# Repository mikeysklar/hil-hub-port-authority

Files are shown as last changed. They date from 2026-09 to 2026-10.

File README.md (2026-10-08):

# hil-hub-port-authority

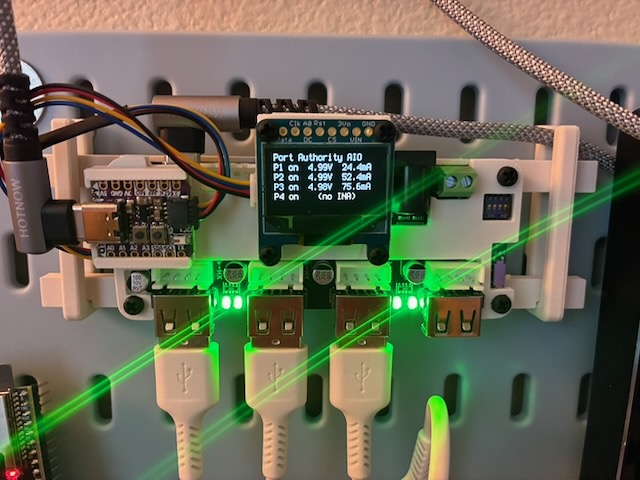
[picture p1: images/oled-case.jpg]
Port Authority hub in the OLED display case, showing live voltage and current per port (https://drive.google.com/file/d/1w-OZUrAUlDJJefoLmWJcbIFCo_5FYicz/view?usp=sharing)


[▶ Watch the video](https://drive.google.com/file/d/1w-OZUrAUlDJJefoLmWJcbIFCo_5FYicz/view?usp=sharing)

Test notes, scripts and cases for the **Port Authority** 4-port USB hub
(Adafruit Smart HIL Hub Rev C), first JLC run, tested 2026-09-24 to 2026-10-01.

USB2514B hub with per-port power switching (`uhubctl`), INA3221 current
monitoring on ports 1-3, two STEMMA QT ports, external 5 V input and DIP
config modes.

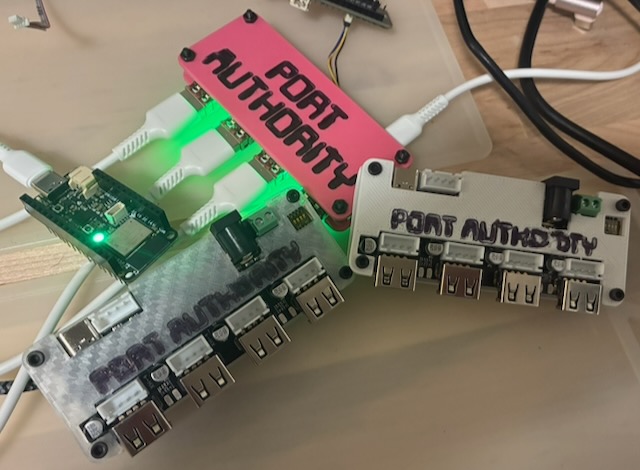
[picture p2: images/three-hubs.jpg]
Three Port Authority hubs in sandwich cases


Short summary: [docs/testing-summary.md](docs/testing-summary.md).

## Works

| Feature | Result |
|---|---|
| Per-port power | Clean cutoffs, Linux and macOS, no sudo |
| Power cycling | Feather M0, RP2040, RP2350, ESP32 V2 |
| Current monitoring | Ports 1-3, within ~5% of a USB meter |
| Port current | 1.17 A+ continuous per port |
| Green port LEDs | Follow port power |
| SW1 reset, external 5 V | Both work |
| DIP `0 0 0 1` | Reports bus-powered |
| EEPROM mode `1 1 1 1` | Works once programmed; custom name and serial |
| STEMMA2 + OLED | Live per-port status display |
| SWD through the hub | RP2350 flash and verify in 11.2 s |
| USB chaining | Works, see concern 2 |

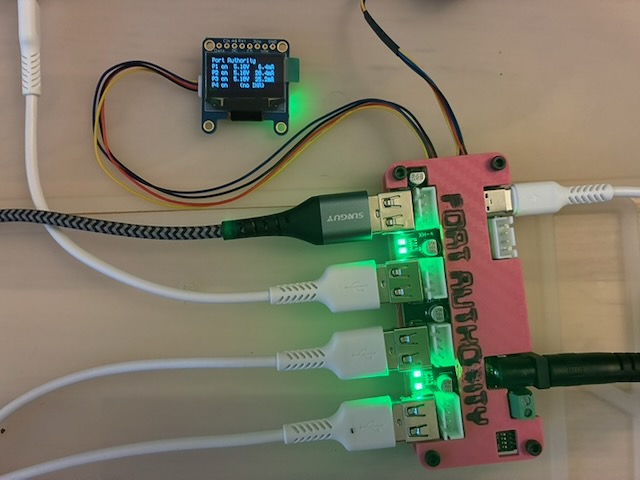
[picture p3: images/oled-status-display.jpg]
OLED on STEMMA2 showing live voltage and current per port


## Concerns

1. **STEMMA QT V+ back-feeds an unpowered controller.** Its 3.3 V rail sits
   at 0.98 V with its port off; a Feather RP2040 lands in the bootloader
   about 1 in 10 boots. Path: hub 3.3 V through the BSS138 body diode and
   QT-side pull-ups onto V+. With only the V+ wire cut: 0 V, 33/33 clean.
   Fix: a diode on STEMMA1 V+, controller on STEMMA1, add-ons on STEMMA2.
   Now: keep the controller always powered.
2. **A chained hub with an ESP32 V2 never recovers after its upstream port
   is cut.** It loops connect/disconnect forever. Fine empty, with native-USB
   boards, or with the V2 on the top-level hub. Keep USB-serial boards on the
   top-level hub.

## Doesn't work

- SMBus DIP mode `1 1 1 0`: hub never enumerates. Parked.
- EEPROM mode as shipped: the EEPROM is blank. Program it with
  `test-scripts/eeprom_write.py`.
- Pi 4 plus drive on one port browns out at 1.24 A peaks.

## Untested

- I2C chaining (needs the A0 jumper)
- Red fault LED
- JST-XH connectors

## Linux setup

Full notes: [docs/host-setup.md](docs/host-setup.md).

- `apt install uhubctl` plus udev rules for the hub and the per-port
  `disable` files. Don't use `uhubctl -S`.
- Address boards by `/dev/serial/by-path`, not `ttyACM` numbers.
- SWD on RP2350 needs the [raspberrypi openocd fork](https://github.com/raspberrypi/openocd).

## Repo

| Path | Contents |
|---|---|
| [docs/](docs/) | findings, full test log, test plan, host setup, summary |
| [test-scripts/](test-scripts/) | test scripts, see its README |
| [case/sandwich/](case/sandwich/) | two-plate case: FreeCAD script, FCStd, STEP, 3MF |
| [case/skadis/](case/skadis/) | IKEA SKADIS frame: FreeCAD script, FCStd, STEP, 3MF, STL |
| [case/display/](case/display/) | top plate with QT Py ESP32-S3 cradle and OLED mount, rail frame, heat-set inserts: FreeCAD script, FCStd, STEP |

Build a case with `freecadcmd build_case.py`; it also writes the STLs left
out of the repo.

| | |
|---|---|
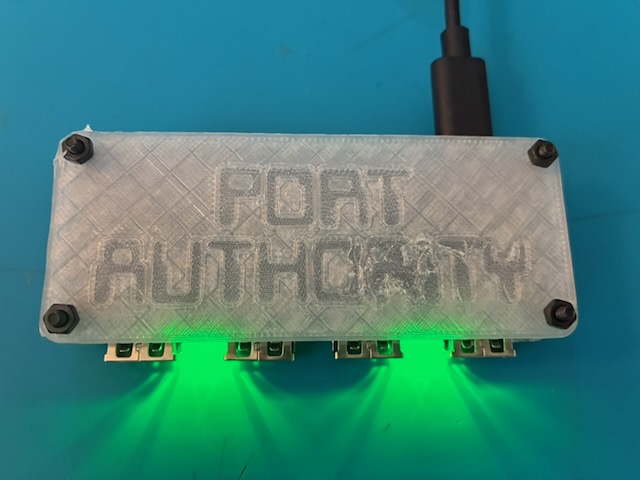
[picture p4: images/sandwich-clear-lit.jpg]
Clear sandwich case with port LEDs lit
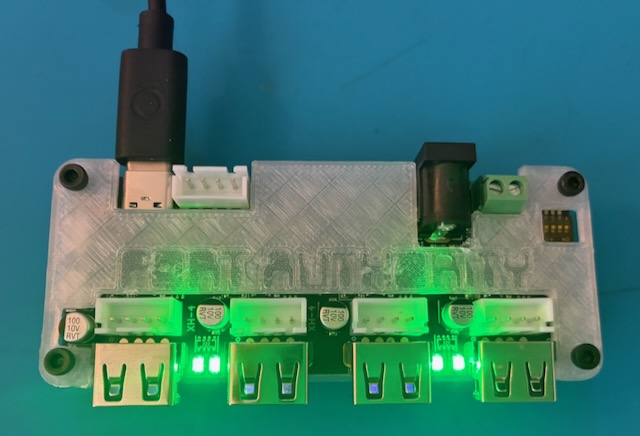
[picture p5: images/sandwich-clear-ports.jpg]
Clear case, connector side
|  |  |
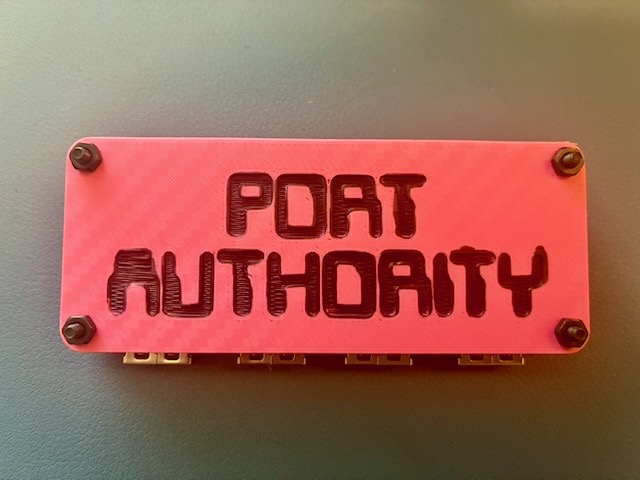
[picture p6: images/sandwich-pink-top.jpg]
Pink sandwich case, top plate
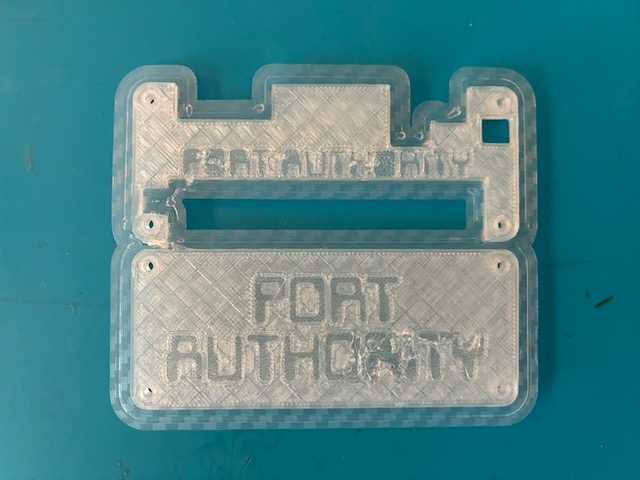
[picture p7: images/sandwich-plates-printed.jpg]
Printed top and bottom plates
|  |  |
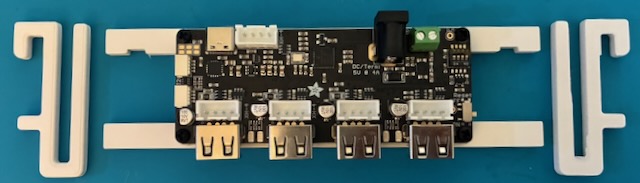
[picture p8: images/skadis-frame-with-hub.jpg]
Hub on the SKADIS frame with pegboard hooks
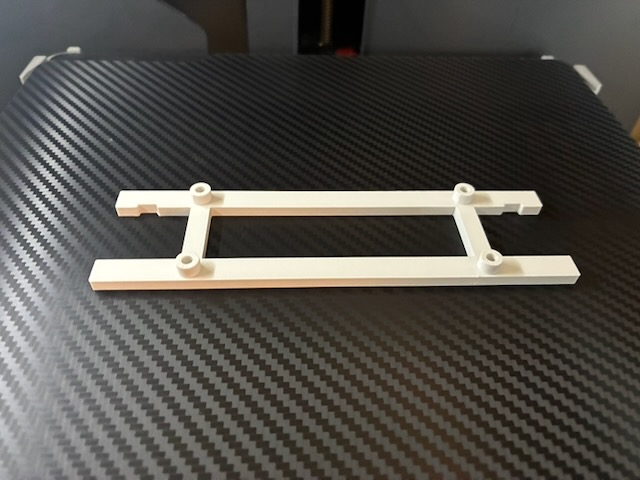
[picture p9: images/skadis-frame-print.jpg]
Printed SKADIS frame with heat-set insert bosses
|  |  |

## License

MIT, see [LICENSE](LICENSE).

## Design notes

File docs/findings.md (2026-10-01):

# Port Authority (Smart HIL Hub Rev C): findings

Running summary for the final report. Evidence and raw output for every row
are in `test-log.md` and `results/`; scripts in `test-scripts/`. Boards tested:
hub A and hub B from the 10-board JLC run, design at commit `461a9006b`.

Status: **Works** confirmed on hardware, **Problem** confirmed, **Open**
not yet tested or not conclusive.

## Hub features

| Feature | Status | Result |
|---|---|---|
| USB enumeration (USB2514B, Multi-TT, 4 ports) | Works | `0424:2514`, TT per port, per-port power and over-current reported |
| Per-port power switching (uhubctl) | Works | Every cutoff clean on both hubs (port reads `0000 off`, board drops, VBUS 0.000 V measured) |
| Hub reset slide switch SW1 | Works | Hub and all ports drop and return; ports are power-cycled too |
| I2C via STEMMA QT, INA3221 at 0x40 | Works | ID registers read `TI` / `3220` |
| Current monitoring, ports 1-3 | Works | Channel N = port N, no crosstalk, 0 mA / 0 V when off; port 4 unmonitored by design |
| External 5 V input (barrel jack) | Works | Hot-plug without disconnect; 4 A supply as stiff as USB-C |
| Bus-powered mode, DIP `0 0 0 1` | Works | Reports `0xa0` Bus Powered, MaxPower 100 mA; per-port switching unchanged. Default `0 0 0 0` reports Self Powered regardless of source, by design |
| USB serial number | Works with EEPROM | Ships with none (two hubs only told apart by USB path). With a programmed EEPROM and DIP `1 1 1 1` the hub reports a serial, e.g. `PA-A` |
| STEMMA2 pass-through | Works | OLED on STEMMA2 scans at 0x3D alongside the INA3221 at 0x40, same bus as STEMMA1 |
| INA3221 accuracy vs meter | Rough check | Battery pack charging on port 2: INA3221 1.15-1.17 A, user's meter 1.2 A (within ~5%). One point only; no low-current check |
| Port LEDs, green | Works | Follows uhubctl port power on/off (user, daily use) |
| Over-current limit and red LED | Works well enough, red not pursued | Ports deliver at least 1.17 A continuously, beyond the ~1 A design target. Red LED never triggered and not tested further (decision 2026-10-01). Red = AP22653 FAULT (also OCS to the hub), after a ~6 ms blanking time, auto-recovering. Battery pack held 1.17 A for 30 s with green LED and no OC reported; Pi 4 + drive peaked 1.10-1.24 A briefly without a fault. |
| Port power under heavy load | Note | Pi 4 + external drive on one port: 0.65 A idle, 0.9-1.0 A busy, peaks to 1.24 A; port sagged to 3.87 V and the Pi browned out and rebooted twice with no fault flagged. Whole-hub supply sagged too (another port 5.10 V to 4.69-4.82 V) on the 4 A barrel. Guide: Pi-class loads are at this port's edge |
| SMBus mode, DIP `1 1 1 0` | Problem, parked | Hub stays off USB but never answers at 0x2C. See problems below |
| EEPROM mode, DIP `1 1 1 1` | Works once programmed | EEPROM ships blank and the hub then fails to enumerate. `eeprom_write.py` (hub held in reset with SW1, DIP 1 2 3 on) wrote a datasheet-default image with strings; hub A now enumerates as Adafruit Industries / Port Authority / PA-A, Multi-TT, all ports working |
| JST-XH per-port connectors | Open | |
| Chaining two hubs, USB | Works, with a restriction | Hub B on hub A port 4: nested uhubctl path `1-1.4` works, hub B ports switch 5/5, cutting hub A port 4 power-cycles hub B and its boards (empty 6/6, Feather RP2040 5/5, thumb drive 5/5). **Restriction:** with an ESP32 V2 on hub B, hub B never recovers from that cut (see problems). Keep USB-serial boards on the top-level hub, or switch their own port instead |
| Chaining two hubs, I2C | Open | Needs hub B's INA3221 A0 jumper bridged (0x41) |
| I2C display on STEMMA | Works | Adafruit 326 (0.96" 128x64 SSD1306, 0x3D) on STEMMA2: `controller/oled_ports.py` shows V/mA for ports 1-3 from the INA3221; `oled_push.py` sends on/off for all 4 from uhubctl. Port changes show within about a second |
| SWD / openocd through the hub | Works | Feather RP2350: attach, `reset halt`, resume; `cannot read IDR` with the port off. 30/30 clean power cycles with the probe attached (no back-feed). RP2350 needs the raspberrypi openocd fork |
| macOS | Works (user report) | Daily use on a Mac mini M4 Pro, macOS 26.6.2, Homebrew uhubctl 2.6.0, no sudo. Power control, bootloader entry and hard resets fine with Feather RP2350, Feather ESP32-S3, Feather RP2040, QT Py ESP32-S3. Hub was three deep behind two Realtek hubs |

## Problems found

| Problem | Status | Detail |
|---|---|---|
| STEMMA QT back-feeds an unpowered controller | Problem, fix found | 0.98 V on the controller's 3.3 V rail with its port off; about 1 in 10 ROM bootloader boots on the Feather RP2040 Adalogger (7/70 + 1/6 + 1/20 + 1/4 with cable; 70/70 clean without). Path: hub 3.3 V, hub-side pull-up, BSS138 body diode, STEMMA-side pull-up, V+. With only the cable's V+ wire cut: 0 V, 33/33 clean (2026-10-01). Fix (ladyada): diode on STEMMA1 V+, controller to hub only; controller on STEMMA1, add-ons on STEMMA2. Real diode and other controllers untested |
| Linux keeps USB-serial boards listed after power-off | Fixed (host setup) | With `uhubctl -S` the kernel is not told. Fixed by the udev rule for the per-port `disable` files; ESP32 V2 now drops in 5 ms |
| Intermittent INA3221 read timeouts | Not the hub | Followed the controller's old dev firmware (SDIO build + SD benchmark). 0 errors in 60 reads after flashing CP 11.0.0-alpha.1 |
| Barrel jack suspected | Not the cause | Coincided with the STEMMA cable coming loose. Cheap USB-to-barrel adapter does dip the rail more (4.77 V vs 4.98 V) but stays in spec |
| Chained hub loops after its upstream port is cut, with an ESP32 V2 on it | Open, workaround | Hub B enumerates, `hub_ext_port_status failed (err = -71)` ~0.1 s later, disconnects, repeats forever. Same bus-powered or on its barrel, after a hub B reset, with autosuspend off. Not current: same ~900 mA capacitor spike as an RP2350, the V2's extra ~140 mA comes ~1 s later. Suspect (untested): its CH9102 connects at full speed the instant power arrives, mid hub start-up. Fine on the top-level hub (days of use, survives hub A resets). Workarounds: switch the V2's own port; or power hub B ports on one at a time |
| SMBus mode does not start | Open, parked | DIP `1 1 1 0`: off USB, no answer at 0x2C, host sees a failed low-speed device at every reset. A blank EEPROM caused the same signature in `1 1 1 1`, fixed by programming it; why SMBus mode matches it is unknown. Probing the bus during reset left SCL held low |

## Host setup needed (for the guide)

- `uhubctl` package, udev rule for vendors `0424` and `0bda` (plugdev), and
  the rule for the per-port `disable` files (see `test-log.md`).
- openocd: stock 0.12.0 works for RP2040 only; RP2350 needs the
  raspberrypi fork (`~/.local/openocd-rp2350` on bene, copied from bravo).
- Mount board drives over SSH with `gio mount` through the desktop session.

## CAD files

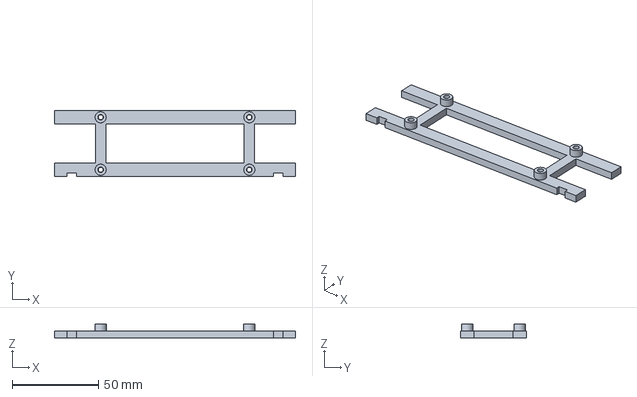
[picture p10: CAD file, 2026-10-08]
case/display/frame.step
140.0 x 38.5 x 8.00 mm

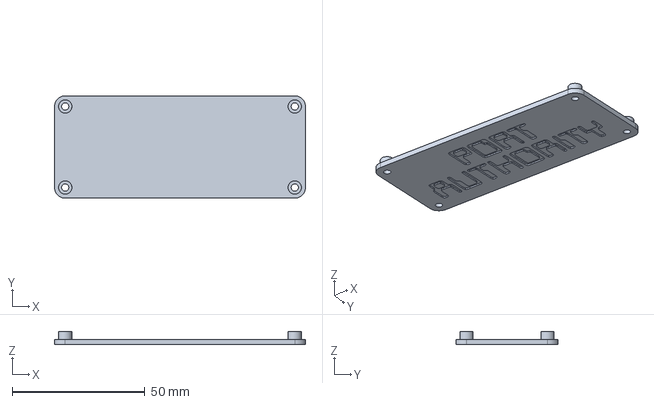
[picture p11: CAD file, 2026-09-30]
case/sandwich/bottom_plate.step
94.4 x 38.6 x 5.00 mm

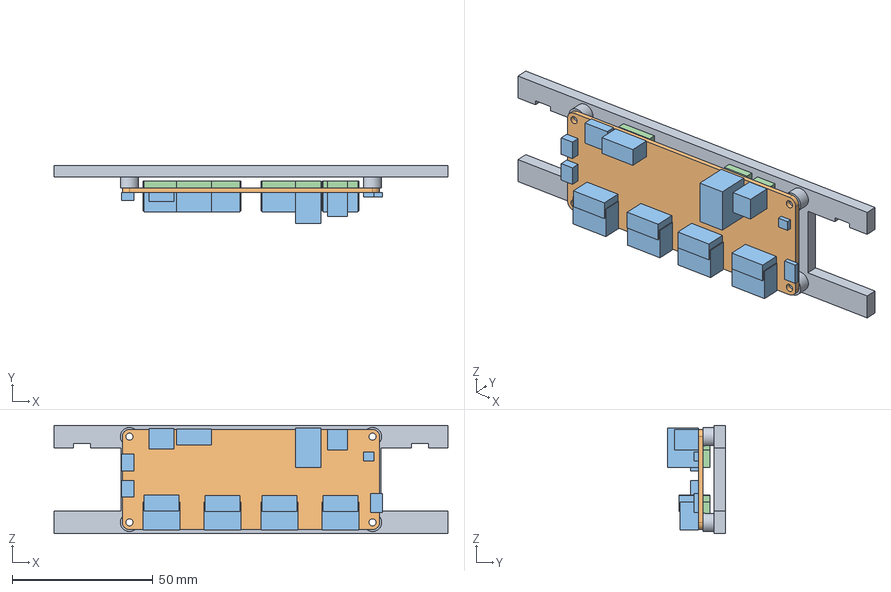
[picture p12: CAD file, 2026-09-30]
case/skadis/skadis_case.FCStd
140.0 x 20.6 x 38.5 mm
Frame
HubPCB
HubParts
HubLeads

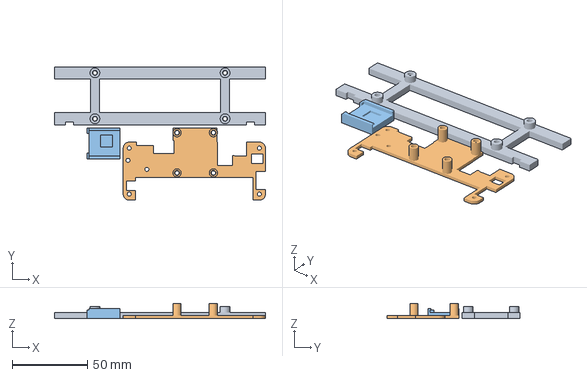
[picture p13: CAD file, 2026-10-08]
case/display/display_case-Frame.3mf
140.0 x 88.5 x 10.0 mm

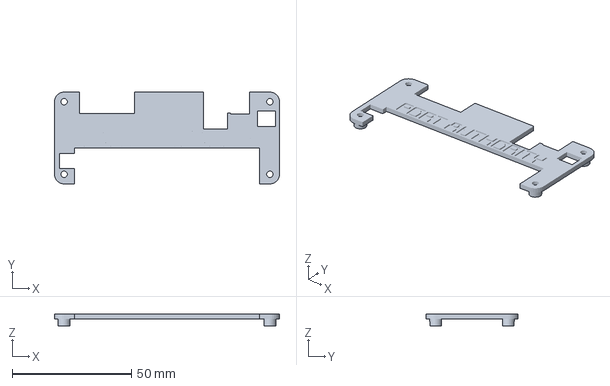
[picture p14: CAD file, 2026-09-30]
case/sandwich/sandwich_case-TopPlate.3mf
94.4 x 38.6 x 4.90 mm

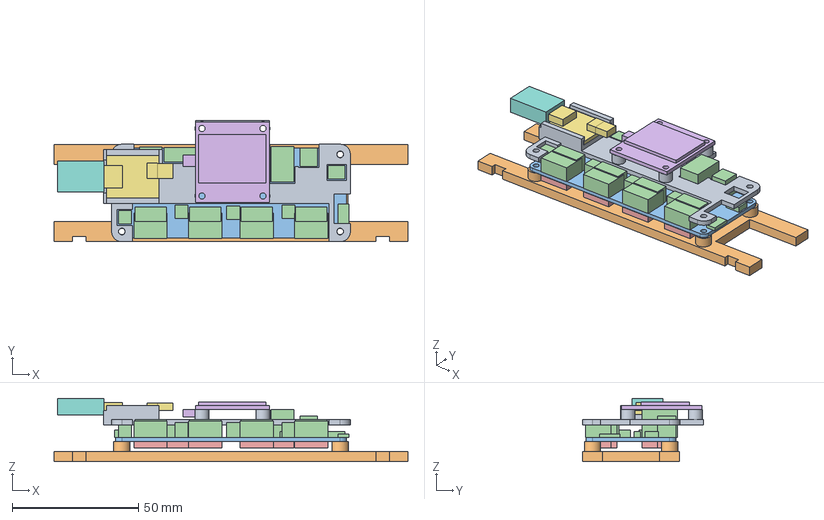
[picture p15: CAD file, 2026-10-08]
case/display/display_case.FCStd
140.0 x 48.0 x 25.0 mm
TopPlate
Frame
HubPCB
HubParts
HubLeads
Oled
QtPy
QtPlug

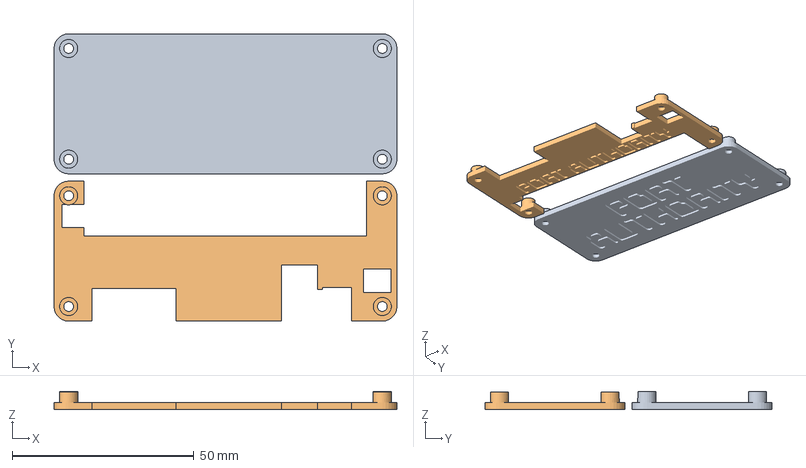
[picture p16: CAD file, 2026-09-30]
case/sandwich/sandwich_case-BottomPlate.3mf
94.4 x 79.1 x 5.00 mm

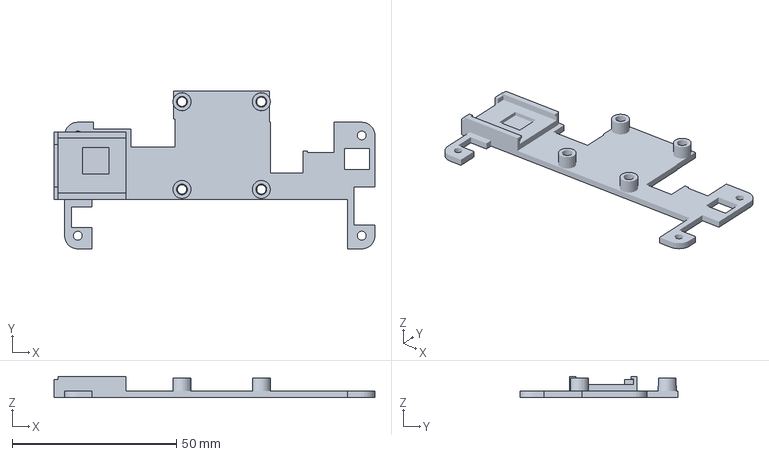
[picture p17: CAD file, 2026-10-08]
case/display/display_case-TopPlate.3mf
97.6 x 48.0 x 6.50 mm

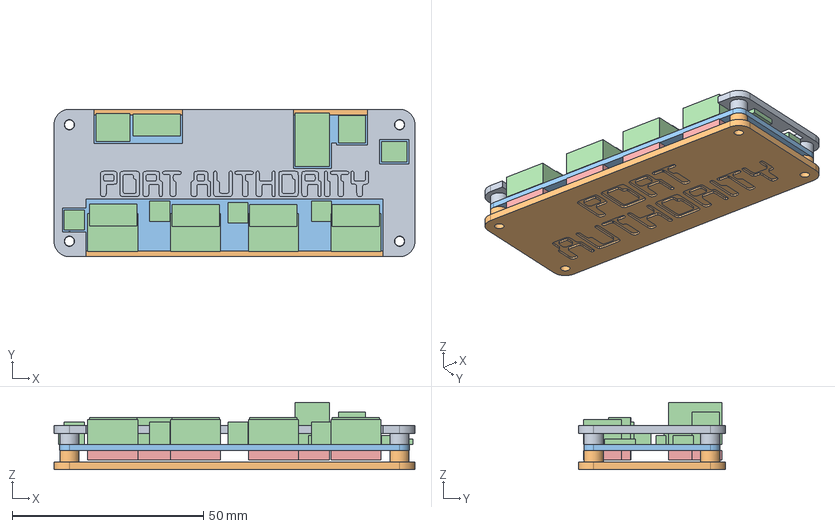
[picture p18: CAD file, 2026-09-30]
case/sandwich/sandwich_case.FCStd
94.4 x 38.6 x 17.6 mm
TopPlate
BottomPlate
HubPCB
HubParts
HubLeads

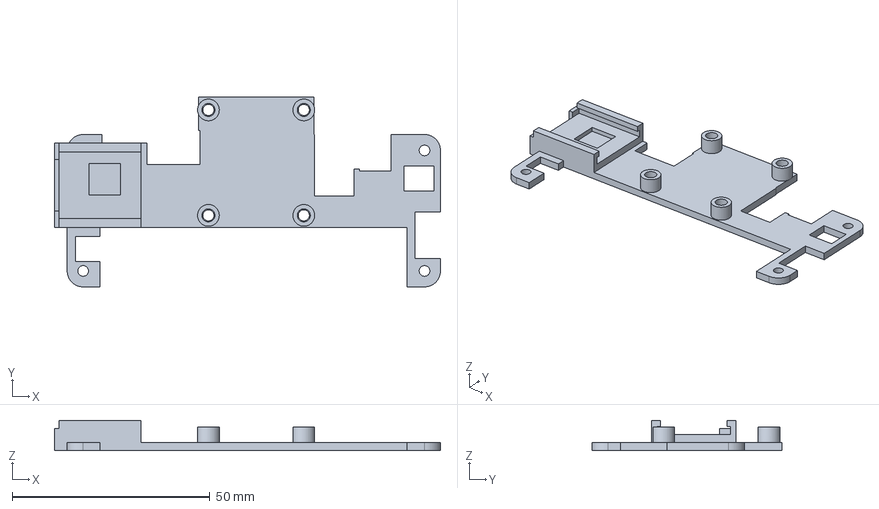
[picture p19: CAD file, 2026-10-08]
case/display/top_plate.step
97.6 x 48.0 x 7.60 mm

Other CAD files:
case/skadis/skadis_frame.step
case/skadis/skadis_frame_print.stl
case/skadis/skadis_case-Frame.3mf
case/sandwich/top_plate.step

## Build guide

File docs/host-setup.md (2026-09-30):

# Port Authority hub on bene: setup notes

First JLC test run (10 boards). One hub plugged into bene.local, 2026-09-24.

## Host

- bene: Ubuntu 26.04.1 LTS, kernel 7.0.0-31-generic, x86_64
- user `sklarm` already in `plugdev` and `dialout`

## What the hub enumerates as

- Microchip USB2514, `0424:2514`, USB 2.0, 4 ports, `ppps` (per-port power switching)
- USB path `1-2` (bene root hub port 2)
- Test board: Feather RP2040 Adalogger `239a:815e`, serial `DF6380824F7A1430`, on port 1
- Serial by path: `/dev/serial/by-path/pci-0000:00:14.0-usb-0:2.1:1.0`

## Setup done

1. Installed uhubctl from apt (bravo has 2.5.0-1; bene got 2.6.0-3):

   ```sh
   sudo apt-get install -y uhubctl
   ```

2. udev rule so uhubctl runs unprivileged. Same as bravo's, plus the Microchip
   vendor ID for the new hub. `/etc/udev/rules.d/52-uhubctl.rules`:

   ```
   SUBSYSTEM=="usb", ATTR{idVendor}=="0bda", MODE="0664", GROUP="plugdev"
   SUBSYSTEM=="usb", ATTR{idVendor}=="0424", MODE="0664", GROUP="plugdev"
   ```

   ```sh
   sudo udevadm control --reload && sudo udevadm trigger --attr-match=subsystem=usb
   ```

   Check: `ls -l /dev/bus/usb/001/<hub devnum>` shows `root plugdev crw-rw-r--`.

3. openocd for SWD through the hub (2026-09-29). The Raspberry Pi Debug
   Probe (`2e8a:000c`) is already `root:plugdev` via
   `/etc/udev/rules.d/60-picotool.rules` (all `2e8a` devices, added
   2026-09-25), so no sudo at run time. The package's own `60-openocd.rules`
   does not list `2e8a`. Stock package:

   ```sh
   sudo apt-get install -y openocd
   ```

   Stock 0.12.0 has `rp2040.cfg` but **no `rp2350.cfg`**. For the RP2350 the
   raspberrypi fork is needed. bravo's build (`0.12.0+dev-g098b86f`, built on
   Ubuntu 24.04) runs unchanged on bene, so it was copied rather than rebuilt:

   ```sh
   ssh bravo.local 'tar -C ~/.local -czf - openocd-rp2350' | tar -C ~/.local -xzf -
   ```

   Use it with its own scripts directory:

   ```sh
   OCD=~/.local/openocd-rp2350
   $OCD/bin/openocd -s $OCD/share/openocd/scripts \
     -f interface/cmsis-dap.cfg -f target/rp2350.cfg -c "adapter speed 5000"
   ```

   Check: `SWD DPIDR 0x4c013477` and both `rp2350.cm0` / `cm1` examined.

## Workarounds and gotchas

- **sudo needs a password on bene.** Installs are an attended step; `sudo -n`
  fails with "interactive authentication is required".
- **The first `! ssh -t bene.local '...'` one-liner install did nothing.** No
  package, no rule file, nothing in apt history. Running the commands directly
  in a shell on bene worked.
- **`/usr/sbin` is not on PATH for non-interactive ssh**, so
  `ssh bene.local uhubctl` gives "command not found". Use
  `export PATH=$PATH:/usr/sbin` or call `/usr/sbin/uhubctl`.
- **The installed rule file has the `0424` line split in two** (paste wrap):

  ```
  SUBSYSTEM=="usb",
    ATTR{idVendor}=="0424", MODE="0664", GROUP="plugdev"
  ```

  It still works because udev reads the second line as its own rule, but that
  rule matches vendor `0424` on any subsystem. Rejoin it onto one line.
- **sysfs port control, fixed 2026-09-28.** Without write access to the
  port `disable` files, every switching call prints `Failed to set port status
  by writing to /sys/bus/usb/devices/1-2:1.0/1-2-port1/disable (Permission
  denied)` and falls back to libusb. Power switches, but the kernel is not told:
  devices behind USB-UART bridges (ESP32 V2's CH9102) stay listed while the
  port is off. **Do not use `-S` to silence it.** Install the rule below
  instead (taken from uhubctl's own `udev/rules.d/52-usb.rules`, kernel 6.0+).
  It also rejoins the split `0424` line above. Run in a shell on bene, not via
  `ssh -t`:

  ```sh
  sudo tee /etc/udev/rules.d/52-uhubctl.rules >/dev/null <<'EOF'
  SUBSYSTEM=="usb", ATTR{idVendor}=="0bda", MODE="0664", GROUP="plugdev"
  SUBSYSTEM=="usb", ATTR{idVendor}=="0424", MODE="0664", GROUP="plugdev"
  SUBSYSTEM=="usb", DRIVER=="hub|usb", RUN+="/bin/sh -c \"chown -f root:dialout $sys$devpath/*port*/disable || true\"", RUN+="/bin/sh -c \"chmod -f 660 $sys$devpath/*port*/disable || true\""
  EOF
  sudo udevadm control --reload && sudo udevadm trigger --attr-match=subsystem=usb
  ```

  Check: `ls -l /sys/bus/usb/devices/1-2:1.0/1-2-port1/disable` shows
  `root dialout -rw-rw----`, and `uhubctl -l 1-2 -p 1 -a off` prints no
  permission warning. User must be in `dialout`.

- **Mounting a board's drive over SSH.** `udisksctl mount` is refused
  (`NotAuthorizedCanObtain`, the ssh session has no seat). Going through the
  logged-in desktop session's gvfs works without sudo:

  ```sh
  export DBUS_SESSION_BUS_ADDRESS=unix:path=/run/user/1000/bus
  gio mount -d /dev/sdX1        # CIRCUITPY or RPI-RP2
  gio mount -u /run/media/sklarm/CIRCUITPY
  ```

  Needs the desktop login on seat0 to exist. Right after a bootloader or
  re-enumeration, retry for a second or two: the volume is not known to gvfs
  immediately (`No volume for given ID`).

## Verified

- `uhubctl -l 1-2` unprivileged: hub listed with `ppps`, Adalogger on port 1
  (`0103 power enable connect`), ports 2-4 `0100 power`.
- Port 1 off (`-a off -r 30 -w 500`): port reads `0000 off`, Adalogger gone from
  `lsusb`.
- Port 1 on: back on the bus in 3 s, new devnum (035 -> 036), all six interfaces
  (CDC, MSC, HID, 2x audio) re-bound.
- Over the REPL after the cycle:
  `microcontroller.cpu.reset_reason` = `POWER_ON`,
  `supervisor.runtime.run_reason` = `STARTUP`. Real VBUS cut, not just a data
  disconnect. Firmware 10.3.0-alpha.3-10-g292758acc8-dirty.

## Not yet tested

- Ports 2-4 with a board attached
- Repeated cycles (one cycle is not a measurement)
- `-a cycle` in one call, and the settle time before the board is usable
- Other nine boards from the run

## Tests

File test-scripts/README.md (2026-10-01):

# Port Authority test scripts

Scripts used for `../test-plan.md`; results in `../test-log.md`. They run on
the Linux host with the hub (bene.local), not on the Mac.

```sh
rsync -a test-scripts/ bene.local:port_authority/test-scripts/
ssh bene.local 'cd port_authority/test-scripts && python3 i2c_scan.py 1-2 4'
```

Needs `pyserial` and `uhubctl` (see `../bene-setup.md`), including the udev
rule that makes the per-port `disable` files writable. The scripts call uhubctl
without `-S` so it uses that sysfs method; with `-S` (raw USB requests) Linux
is not told about the power-off and keeps devices like the ESP32 V2's CH9102
listed after they lose power. Boards are always
addressed by USB path (`1-2` hub, port N), never by `ttyACM` number.

| Script | Test | What it does |
|---|---|---|
| `repl.py` | helper | CircuitPython REPL driver, syncs on `>>> ` first |
| `cycle_ports.py` | T2 | round-robin cycles over several ports, per-board check, stops each port at first failure |
| `cycle_port.py` | T2 | N uhubctl power cycles on one port, checks off/gone/back/POWER_ON (SAMD: UNKNOWN + STARTUP); RP2040/RP2350 ROM bootloader = BOOTROM |
| `reset_reason.py` | T2 | print reset and run reason of a board |
| `i2c_scan.py` | T4 | scan the hub I2C bus from the controller on a hub port |
| `ina3221_id.py` | T4 | read INA3221 ID registers (0xFE, 0xFF, 0x00) |
| `i2c_compare.py` | T4 debug | reads via board.STEMMA_I2C() vs fresh busio.I2C |
| `controller/code.py` | setup | idle sketch for the Adalogger I2C controller (CP 11.0.0-alpha.1) |
| `controller/oled_ports.py` | T12 | `code.py` for the controller: SSD1306 OLED on STEMMA2 shows ports 1-3 V/mA (INA3221) and on/off for all 4 pushed from the host |
| `oled_push.py` | T12 | host side: sends `PA 1101` (uhubctl power bits, ports 1-4) to the controller every second |
| `oled_demo.sh` | T12 | switches ports off/on one at a time for the OLED demo |
| `watch_hub.sh` | T7 | print every change in which devices are on a hub, for N seconds |
| `ina3221_volts.py` | T5/T8 | INA3221 bus voltage and current on ports 1-3, min/avg/max |
| `ina_ramp.py` | T8 debug | fast INA3221 capture of a port VBUS ramp or rail dip during uhubctl power-on |
| `backup_repl.py` | setup | back up every file on a board over the serial REPL (base64), for boards with no drive |
| `ina_watch.py` | T6 | per-second V and mA min/avg/max on one port while it powers a load; `-1` watches without switching |
| `ina_inrush.py` | T5/T11 | fast INA3221 current capture of a board's power-on on ports 1-3, ~288 us/sample for ~2.3 s |
| `chain_cut.py` | T11 | cut the upstream port of a chained hub; compares a native-USB board's uptime before and after |
| `ina_channel_map.py` | T5 | map INA3221 channels to ports by switching one port off at a time |
| `cold_compare.sh` | T4 debug | uhubctl cold boot of the controller, then i2c_compare.py, N times |
| `smbus_probe.py` | T9 | scan, then block-read register 0x00 at the hub's SMBus address 0x2C (DIP `1 1 1 0`) |
| `smbus_race.py` | T9 debug | probe 0x2C every 20 ms for N seconds while SW1 resets the hub, prints ACK/NACK changes |
| `eeprom_dump.py` | T9 | read-only hex dump of the hub config EEPROM (24LC02, 0x50); needs DIP 1-3 on |
| `eeprom_write.py` | T9d | write a USB2514B config image with custom manufacturer/product/serial strings, then verify; hub held in reset with SW1 |
| `i2c_lines.py` | T9 debug | sample SCL/SDA levels on the controller to spot a bus held low |
| `uf2_to_bin.py` | T13 | convert a UF2 to a raw image for openocd `program`; prints family, base and size |
| `swd_port.sh` | T13 | SWD attach with the port off (expect fail) and on (reset halt, resume), RP2350 + Debug Probe |

`ina3221_id.py` retries each read up to 5 times and prints every `ETIMEDOUT`,
see the T4 open item in `../test-log.md`.

Controller location: scripts default to the Adalogger on hub port 4. Set
`PA_CTRL=<usb path>` (for example `PA_CTRL=1-1` when it is plugged straight
into bene) to point them at the controller elsewhere.

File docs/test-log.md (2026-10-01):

# Port Authority (Smart HIL Hub Rev C): test log

Plan: `test-plan.md`. Host bene.local, hub USB path `1-2`.

## Setup, 2026-09-25

- S1: DIP SW2 all off (CFG_SEL 00, EEPROM unpowered, hub I2C isolated).
- S2: Adalogger moved to port 4, STEMMA QT cable to hub STEMMA1 (the one nearer the USB-A row).
- S3: Adalogger now `1-2.4`, tty `/dev/serial/by-path/pci-0000:00:14.0-usb-0:2.4:1.0`.
  Hub devnum 109 (was 34 on 09-24; it has re-enumerated since).

```
$ uhubctl -l 1-2
Current status for hub 1-2 [0424:2514, USB 2.00, 4 ports, ppps]
  Port 1: 0100 power
  Port 2: 0100 power
  Port 3: 0100 power
  Port 4: 0103 power enable connect [239a:815e Adafruit Feather RP2040 Adalogger DF6380824F7A1430]
```

## T1. Enumeration and descriptors, 2026-09-25: PASS (with findings)

`lsusb -v -d 0424:2514`, DIP all off, powered from upstream USB only (confirmed).

| Field | Value | Meaning |
|---|---|---|
| idVendor:idProduct | `0424:2514`, bcdDevice `b.b3` | USB2514B internal defaults |
| iManufacturer / iProduct / iSerial | 0 / 0 / 0 | **No strings, no serial number** |
| bDeviceProtocol | 2, alt setting 1 = TT per port | Multi-TT |
| bmAttributes | `0xe0` Self Powered, Remote Wakeup | from CFG_SEL 00 |
| MaxPower | 2 mA | |
| wHubCharacteristic | `0x0009` | per-port power switching, per-port over-current |
| bPwrOn2PwrGood | 50 x 2 ms = 100 ms | |
| DeviceRemovable | `0x00` | all ports removable (NON_REM straps 00 via R27, R7) |
| PortPwrCtrlMask | `0xff` | |

Findings:

1. **Reports Self Powered in default mode regardless of the actual source.**
   Matches Table 5-1 (CFG_SEL 00 = self-powered) and the Rev C schematic,
   where `LOCAL_PWR` is only a 100K pull-down and not tied to the TPS2117 `ST`
   output. When run from USB alone, the host believes 500 mA is available per
   port. DIP 4 on (CFG_SEL 10) should give bus-powered reporting; T9.
2. **No serial number.** Two hubs cannot be told apart by descriptor; address
   them by USB path (`uhubctl -l 1-2`), which matters for chaining (T11).
3. Descriptor and port status agree with uhubctl: `ppps`, port 4 connected.

<details><summary>Full lsusb -v</summary>

```
Bus 001 Device 109: ID 0424:2514 Microchip Technology, Inc. (formerly SMSC) USB 2.0 Hub
Negotiated speed: High Speed (480Mbps)
Device Descriptor:
  bcdUSB               2.00
  bDeviceClass            9 Hub
  bDeviceProtocol         2 TT per port
  idVendor           0x0424 Microchip Technology, Inc. (formerly SMSC)
  idProduct          0x2514 USB 2.0 Hub
  bcdDevice            b.b3
  iManufacturer           0
  iProduct                0
  iSerial                 0
  Configuration Descriptor:
    bmAttributes         0xe0
      Self Powered
      Remote Wakeup
    MaxPower                2mA
Hub Descriptor:
  nNbrPorts             4
  wHubCharacteristic 0x0009
    Per-port power switching
    Per-port overcurrent protection
    TT think time 8 FS bits
  bPwrOn2PwrGood       50 * 2 milli seconds
  bHubContrCurrent      1 milli Ampere
  DeviceRemovable    0x00
  PortPwrCtrlMask    0xff
 Hub Port Status:
   Port 1: 0000.0100 power
   Port 2: 0000.0100 power
   Port 3: 0000.0100 power
   Port 4: 0000.0103 power enable connect
Device Status:     0x0001
  Self Powered
```
</details>

## T4 (part 1). I2C scan, DIP all off, 2026-09-25: PASS

Adalogger on port 4, `board.STEMMA_I2C()` into hub STEMMA1.

```
>>> print([hex(a) for a in i2c.scan()])
['0x40']
```

Identity of 0x40 confirmed from ID registers:

```
0xfe 5449    manufacturer ID "TI"
0xff 3220    die ID, INA3221
0x0 7127     configuration register, power-on default
```

- Only 0x40, as expected with DIP 2/3 off: EEPROM (0x50) and hub SMBus (0x2C)
  are isolated. INA3221 address jumpers A0-A2 open, R15 pulls A0 to GND.
- STEMMA2 pass-through (OLED at 0x3C) still to do.

### T4 open item: intermittent ETIMEDOUT on INA3221 reads

`scan()` always finds 0x40, but register reads (`writeto_then_readfrom`)
sometimes fail with `OSError: [Errno 116] ETIMEDOUT`, in runs:

| run | result |
|---|---|
| ad hoc, 1st session | 3/3 reads ok |
| `ina3221_id.py` after `i2c_scan.py` (x2) | all reads fail, lock left held (script bug, fixed with try/finally) |
| step-by-step session | 1st read fails, 2nd ok |
| 3 sessions in one REPL, deinit between | session 1: 4 fails then ok after a scan; sessions 2-3: all ok |
| `ina3221_id.py` with retry, x3 | run 1 all ok; runs 2-3 all 5 retries fail |

Not deterministic. **Confounded:** the 5 V barrel jack was plugged in during
these runs, exact time unknown. Unknown whether it is the hub (BSS138 level
shifter, 10K pull-ups on both sides), the Adalogger/CircuitPython side, or
the cable. Needs a measured run count on each power source and a control
(same controller, a known-good I2C breakout without the hub).

## T8 (part 1). External 5 V hot-plug, 2026-09-25

5 V barrel jack plugged into X11 while running from USB, Adalogger on port 4.

- No disconnect in the kernel log; hub stayed devnum 109, Adalogger 110.
- `bmAttributes 0xe0` Self Powered, unchanged (as predicted from T1: the hub
  cannot see the power source).
- Port status unchanged: port 4 `0103`.

### T4 open item, continued: narrowed to the first `board.STEMMA_I2C()` object

Barrel jack in, DIP all off. `ina3221_id.py` 20 runs: **20/20 fail**, every
read `ETIMEDOUT`.

Frequency is not the cause: after `board.STEMMA_I2C().deinit()`, a fresh
`busio.I2C(board.SCL, board.SDA, frequency=f)` read 10/10 at each of 400k,
100k, 50k and 10k.

`i2c_compare.py 1-2 4 5`, one REPL session after the usual Ctrl-C/soft reload:

```
CASE A STEMMA_I2C as found ok 0 err 5 0000 [Errno 116] ETIMEDOUT
CASE B STEMMA_I2C again ok 0 err 5 0000 [Errno 116] ETIMEDOUT
CASE C deinit, STEMMA_I2C new ok 5 err 0 5449 None
CASE D busio.I2C 100k ok 5 err 0 5449 None
CASE E busio.I2C 400k ok 5 err 0 5449 None
CASE F STEMMA_I2C after busio ok 5 err 0 5449 None
```

- The first I2C object in the VM fails every hardware transaction; after one
  `deinit()` every later object works, including `board.STEMMA_I2C()` itself.
- `scan()` works even on the bad object because on RP2040 the zero-byte probe
  writes go through bitbangio, not the I2C peripheral
  (`ports/raspberrypi/common-hal/busio/I2C.c`, per subagent, to verify).
  That is why the scan always found 0x40.
- Each failed read costs the 1 s bus timeout (`BUS_TIMEOUT_US`).
- Root cause unknown. Not yet separated: hub vs controller (needs a control
  without the hub), soft reload vs cold boot, barrel jack in vs out.

Research leads (3 subagents: Learn guides, forums, GitHub):

- `adafruit_ina3221` reads with separate `write()` + `readinto()`, not
  `write_then_readinto()`; STEMMA_I2C is fixed at 100 kHz
  (`shared-module/board/__init__.c`). Both per subagent, to verify.
- circuitpython#2635 (open): no I2C bus recovery exists; a bad bus state
  persists until power down.
- Learn "Working with I2C devices": lower clock for clock stretching. Already
  ruled out here.
- Forum t=213402: INA228 I2C failures from high dI/dt switching noise. Lead
  only.

### T4 open item, continued: cold boot clears it, then it comes back

`cold_compare.sh 1-2 4 10 3` (uhubctl power cycle of port 4, 10 s wait,
`reset_reason.py`, then `i2c_compare.py`): **10/10 cycles all cases pass**,
`POWER_ON` every cycle, including case A (first `STEMMA_I2C`).

A few minutes later, no power cycle: `ina3221_id.py` fails every read again
and `i2c_compare.py` shows the same A/B fail, C-F pass pattern.

Controller state that differs between the two: the Adalogger is not running
stock firmware. It runs `10.3.0-alpha.3-10-g292758acc8-dirty` with the
experimental SDIO build (circuitpython PR #11090, `CIRCUITPY_SDIOIO=1`), and
`code.py` is Jeff Epler's SD benchmark: `mount_sd.py` mounts the card over
4-bit SDIO (PIO, GPIO18-23), sleeps 8 s, then writes and reads the card.
In the cold-boot runs the scripts interrupted `code.py` during that 8 s sleep,
so the benchmark I/O never ran. Between the later sessions it ran to
completion. Suspect, not proven: SDIO/PIO/DMA activity leaves the RP2040 I2C0
peripheral in a state that survives soft reloads until a deinit or power
cycle. That would make this a controller firmware issue, not the hub.

### T4 open item, resolved for hub testing: controller firmware swapped

Changes to the Adalogger, 2026-09-25:

1. Backup of CIRCUITPY (19 files, md5 verified) in `adalogger-backup-20260925/`.
2. Flashed CircuitPython **11.0.0-alpha.1** (UF2 sha256
   `6dd88ceb10d6868bcd7709623bc8bfff6ebdfafa2519ac3c6d844ed0a42a7349`),
   1200-baud touch then copy to RPI-RP2. `boot_out.txt` confirms
   `11.0.0-alpha.1 on 2026-09-24`, board ID and UID `DF6380824F7A1430`.
3. `code.py` replaced with the idle sketch `test-scripts/controller/code.py`
   (no SD, no I2C, no pins). No `boot.py` existed. `mount_sd.py`,
   `settings.toml` and the backup files left on the drive, unused.

Result, same hub, same cable, barrel jack still in:

- `i2c_compare.py`: all cases A-F pass, before and after.
- `ina3221_id.py` x20 across 20 soft reloads: **60/60 reads ok, 0 ETIMEDOUT**.
  The old firmware failed 20/20 under the same test.

Conclusion: the hub is not the cause. The failure followed the controller's
firmware/`code.py` (10.3.0-alpha.3 dirty with experimental SDIO running the SD
benchmark). Two variables changed at once (firmware and `code.py`), so this
does not isolate SDIO vs the old build. That split only matters for the SDIO
PR, not for the hub.

## T7. Hub reset (SW1), 2026-09-25: PASS

SW1 is the slide switch next to USB-A port 4 (not DIP 1; a first attempt moved
DIP 1 by mistake, nothing happened, reset back off). SW1 moved to hold for
about 5 s, then back to run. `test-scripts/watch_hub.sh 1-2 90`:

```
16:37:22.353 present: 1-2 1-2.4
16:37:31.745 present: <none>
16:37:37.888 present: 1-2
16:37:39.633 present: 1-2 1-2.4
```

Kernel log:

```
16:37:31 usb 1-2: USB disconnect, device number 109
16:37:31 usb 1-2.4: USB disconnect, device number 123
16:37:37 usb 1-2: new high-speed USB device number 9 using xhci_hcd
16:37:39 usb 1-2.4: new full-speed USB device number 10 using xhci_hcd
```

- Hub and all downstream devices drop while SW1 holds reset, and return on
  release: hub 0 s after release, Adalogger 1.7 s later. New devnums (9, 10).
- **Downstream port power is cut during hub reset.** The Adalogger reports
  `POWER_ON` / `STARTUP` afterwards, so SW1 power-cycles every port at once.
  Consistent with PRTPWR going inactive while `RESET_N` is low.
- Port status after: 1-3 `0100 power`, 4 `0103 power enable connect`.

JP1 (reset test pad) not tested; same net as SW1.

## T2. Per-port power switching, 2026-09-25 (in progress)

### Port 4, Adalogger (CP 11.0.0-alpha.1, idle code.py): 9/10

`cycle_port.py 1-2 4 10` (off `-r 30 -w 500`, 2 s off, on, 10 s settle):

```
n  off   gone  bus_s tty_s devnum reset      run
1  0000  True  1.8   1.9   11     POWER_ON   STARTUP  PASS
2  0000  True  1.8   1.9   12     POWER_ON   STARTUP  PASS
3  0000  True  1.8   2.0   13     POWER_ON   STARTUP  PASS
4  0000  True  0.6   -     14     NO-TTY     -  FAIL
5  0000  True  1.8   1.9   15     POWER_ON   STARTUP  PASS
...
10 0000  True  1.8   1.9   20     POWER_ON   STARTUP  PASS
9/10 pass
```

Control: `microcontroller.reset()` then read back gives
`ResetReason.SOFTWARE`, so the POWER_ON check can fail.

**Cycle 4 booted into the RP2040 ROM bootloader**, not CircuitPython:

```
16:40:45 usb 1-2.4: new full-speed USB device number 14 using xhci_hcd
16:40:45 usb 1-2.4: New USB device found, idVendor=2e8a, idProduct=0003, bcdDevice= 1.00
16:40:45 usb-storage 1-2.4:1.0: USB Mass Storage device detected
```

It stayed in RPI-RP2 until the next power-off; cycle 5 booted normally. It
came up at 0.6 s instead of the usual 1.8 s (the ROM enumerates faster than
CircuitPython). Port switching itself worked every cycle (`0000 off`, device
gone). One in ten is not a rate. Unknown: whether off time, VBUS decay (100 uF
on each port) or the RP2040's boot behavior on a fast power cycle is the
cause. The same board passed 10/10 on port 1 on 09-24 on the old firmware.

Script fix: `cycle_port.py` printed `NO-TTY` and hid the bootloader boot. It
now records VID:PID and reports `BOOTROM`.

### Port 4, 30 cycles at 2 s off and 30 at 5 s off: 27/30 each

Raw output: `results/t2-port4-30x-off2s.txt`, `results/t2-port4-30x-off5s.txt`.

| off time | pass | fails | failed cycles |
|---|---|---|---|
| 2 s | 27/30 | 3 BOOTROM | 11, 13, 16 |
| 5 s | 27/30 | 3 BOOTROM | 1, 8, 20 |
| (earlier) 2 s | 9/10 | 1 BOOTROM | 4 |

- Every cycle switched correctly: `0000 off`, device gone, back on the bus.
  **Port power switching is 70/70.** Every failure is the Adalogger booting
  into the RP2040 ROM bootloader (`2e8a:0003`, up at 0.6 s) instead of
  CircuitPython.
- **Off time does not matter:** 10% at both 2 s and 5 s (7/70 overall). So it
  is not the port's 100 uF failing to discharge.
- All BOOTROM boots recovered on the next power cycle.
- Remaining suspects: the power-on ramp this port delivers (AP22653 soft start
  into 100 uF plus the board's own capacitance) vs RP2040 flash boot, or the
  board itself. Needs a control: the same kind of cycle on a different
  switchable hub (bene's Realtek `1-6.3.4` has `ppps` and two RP2040 boards).
- Unexplained, minor: device numbers 24-26 and 28 were skipped during the 2 s
  run with no kernel log lines for them.

### Controls on bene's Realtek hubs (0bda:5411, ppps), 30 cycles at 2 s off

| board | hub / port | result | file |
|---|---|---|---|
| Feather RP2040 DVI | `1-6.3.4` port 4 | 30/30, 0 BOOTROM | `results/t2-control-realtek-dvi-30x-off2s.txt` |
| **Adalogger (same board)** | `1-6.3` port 2 | **30/30, 0 BOOTROM** | `results/t2-control-realtek-adalogger-30x-off2s.txt` |
| Adalogger | Port Authority `1-2` port 4 | 63/70, 7 BOOTROM | above |

- Same Adalogger, same firmware, same script: 0/30 bootloader boots on the
  Realtek hub vs 7/70 (10%) on Port Authority port 4. If the rate were 10%
  on both, 0/30 would happen about 4% of the time (0.9^30), so this points at
  the hub side, not proven.
- Still confounded: Port Authority was on the external 5 V barrel jack, the
  Realtek hubs on their own supply; only port 4 of Port Authority tested.
- Leading hypothesis, unmeasured: the VBUS rise on Port Authority's port
  (AP22653 switch into 100 uF plus the board) is slow or non-monotonic enough
  that the RP2040 flash boot fails and the ROM falls back to USB boot. The real
  measurement is a scope on port VBUS during power-on, Port Authority vs
  Realtek.

### Port 4, hub on USB-C power only (barrel jack removed): 30/30

`results/t2-port4-usbonly-30x-off2s.txt`: 30/30 pass, 0 BOOTROM.

| hub power | Adalogger on | BOOTROM |
|---|---|---|
| USB-C + 5 V barrel jack | Port Authority port 4 | 7/70 |
| USB-C only | Port Authority port 4 | 0/30 |
| Realtek hub supply | Realtek `1-6.3` port 2 | 0/30 |

The bootloader boots follow the **external 5 V input**, not the port or the
hub's switching. With the barrel jack in, ports are fed through the
TPS259470A eFuse and the TPS2117 mux's external input; on USB-C only they are
fed from upstream VBUS through the mux's other input. Not yet separated: the
hub's external power path vs the particular 5 V supply used (make/rating
unrecorded). 0/30 vs a 10% rate is about 4% likely by chance, so a repeat
with the barrel jack back in is the confirming run.

### Supply check and power-on capture with the barrel jack in (USB 2 A adapter to barrel)

Static, `ina3221_volts.py 1-2 4 20`, ports 1-3 empty: **5.016 V** on all
three channels, every sample. The adapter is not sagging at rest (eFuse UVLO
about 4.48 V per the Rev A review, same R values in Rev C).

Fast capture, `ina_ramp.py` (INA3221 one channel, bus only, 140 us
conversion, about 254 us/sample, 3000 samples; config restored to 0x7127
after). Shunts are after each AP22653 switch, so channel N reads port N VBUS.
Raw CSVs: `results/ramp-jack-in-ch*-p1-*.csv`.

Port 1's own ramp, port 1 switched on, empty port (5 trials):

| trial | 0.5 V to 4.5 V | min after reaching 4.5 V | max | end |
|---|---|---|---|---|
| 1 | 489 us | 4.776 | 5.088 | 5.016 |
| 2 | 488 us | 4.544 | 5.088 | 5.016 |
| 3 | 733 us | 4.800 | 5.096 | 5.016 |
| 4 | 732 us | 4.680 | 5.088 | 5.016 |
| 5 | 732 us | 4.776 | 5.096 | 5.024 |

Trial 2 samples: 0.19, 1.85, 3.86, 4.54, 4.86, 4.96, 5.00 V at 254 us steps,
so about 1.5 ms from off to 5.0 V. Rise time resolution is one sample
(254 us); the 488 vs 732 us split is sample quantization.

Shared rail seen on port 2 while port 1 switches on (5 trials): steady 5.016 V,
**dips to 4.768-4.784 V** for about 1 ms at switch-on, overshoots to about
5.09 V, settles at 5.02 V. Trial 1: 5.016, 4.904, 4.784, 4.864, 4.952, 4.992,
5.032 V. The dip stays above the eFuse UVLO in all 5.

Script fix: the first summary line labelled `min(v)` as "start"; it now prints
first, min, max and end separately.

Caveat: an empty port. The Adalogger adds its own input capacitance, so a
loaded port's inrush and dip will be larger. Port 4 (where the BOOTROM boots
happened) cannot be captured this way, it has no INA3221 channel and it
powers the controller.

### Same captures on USB-C power only (barrel jack unplugged)

Raw CSVs: `results/ramp-usb-only-ch*-p1-*.csv`.

| measurement (port 1 switched on, empty) | barrel jack in | USB-C only |
|---|---|---|
| static rail, ports 1-3 | 5.016 V | 5.120 V |
| rail dip on port 2 (5 trials) | to 4.768-4.784 V (-0.23 to -0.25 V) | to 4.976-4.984 V (-0.14 V) |
| rail overshoot after dip | to 5.088-5.096 V (+0.07 V over steady) | none (max 5.128-5.136, steady 5.12) |
| port 1 min after first reaching 4.5 V | 4.544-4.800 V | 4.728-4.936 V |
| port 1 off to 4.5 V | 1 to 3 samples of 254 us | same |

- The external input is about 0.1 V lower at rest, dips about 1.7x deeper at
  switch-on, and overshoots afterwards. USB-C only dips less and does not
  overshoot. That matches the external path having more source impedance
  (adapter, barrel cable, eFuse) and a regulation loop that rings.
- Even the worst dip (4.77 V) is far above what the Adalogger's 3.3 V LDO
  needs, so a simple 5 V brownout does not explain the ROM bootloader boots
  on its own. Not measured: the port VBUS and the board's 3.3 V rail during
  the first ~1.5 ms with a board attached, at better than 254 us resolution.
  That needs a scope.
- Practical conclusion for now: with this USB-to-barrel 2 A adapter, 7/70
  bootloader boots; on USB-C only 0/30. Next cheap check: a proper 5 V barrel
  supply.

### 4 A barrel supply, 2026-09-27: run aborted at cycle 6

Static rail 5.120 V (same as USB-C only). Rail dip at port 1 switch-on
4.976-4.992 V, no overshoot (`results/ramp-jack4a-ch2-p1-*.csv`), identical
to USB-C only. Not yet confirmed which input the TPS2117 had selected: the
design has no readout of `ST`.

`cycle_port.py 1-2 4 70 2`: cycles 1-5 pass; **cycle 6 booted to the ROM
bootloader** (`2e8a:0003`, devnum 67, 05:41:57). Then the whole hub dropped
twice, which the script did not survive:

```
05:42:20 usb 1-2: USB disconnect, device number 9
05:42:52 usb 1-2: new high-speed USB device number 68
05:43:07 usb 1-2: USB disconnect, device number 68
05:43:07 usb 1-2: clear tt 4 (9332) error -71
05:43:15 usb 1-2: new high-speed USB device number 70
```

Cause of the two hub drops not known yet (asked whether the supply or cables
were handled at those times). So far on the 4 A supply: 1 BOOTROM in 6.

Script fix: `cycle_port.py` crashed on `SerialException` when the board
vanished mid-read. It now records `SERIAL-ERR`, continues, and notes when the
hub itself was missing during a cycle.

### Hub B (second Rev C board), 4 A barrel supply, 2026-09-27

Swapped in hub B: same bene port (`1-2`), Adalogger on port 4, STEMMA1 cable,
DIP all off, 4 A barrel supply. Hub A is the board used for everything above.
`cycle_port.py 1-2 4 70 2 stop` (stop at first BOOTROM):

**19/20, BOOTROM on cycle 20** (`results/t2-hubB-port4-jack4a-until-bootrom.txt`).

Summary of every port-power cycle run with the same Adalogger (CP 11.0.0-alpha.1):

| hub | hub power | BOOTROM boots |
|---|---|---|
| Port Authority A | USB-C + USB 2 A adapter on barrel | 7/70 |
| Port Authority A | USB-C only | 0/30 |
| Port Authority A | USB-C + 4 A barrel supply | 1/6 (run aborted) |
| **Port Authority B** | USB-C + 4 A barrel supply | **1/20** |
| Realtek `1-6.3` | its own supply | 0/30 |

- **The problem follows to a second Rev C board**, so it is the design (or
  both boards equally), not one bad assembly.
- A stiffer 4 A supply did not fix it.
- The only clean Port Authority run is USB-C only (0/30, about 4% likely by
  chance at a 10% rate). Firming that up on hub B is the next discriminator:
  if USB-C only stays clean over 45+ cycles, the external power input path
  (eFuse, TPS2117 switchover) is implicated.

### Multi-board round-robin on hub B (4 A barrel supply), 2026-09-27

`cycle_ports.py` (one port at a time, stop each port at first failure).
Boards: port 1 Feather RP2040 (HID only, checked by VID:PID), port 2 Feather
RP2350 (REPL), port 3 Feather ESP32 V2 (CH9102 bridge, REPL), port 4
Adalogger (REPL, STEMMA QT cable to hub STEMMA1). None have batteries.

| port | board | result |
|---|---|---|
| 1 | Feather RP2040 | 15 + 19 passes, no failure (two runs, stopped by hand) |
| 2 | Feather RP2350 | 15 + 18 passes, no failure |
| 3 | Feather ESP32 V2 | fails round 1 in both runs: never leaves the bus in the 2 s off, REPL no answer after 10 s / 20 s settle. Answers normally when checked by hand afterwards. Unexplained |
| 4 | Adalogger | 3 passes, BOOTROM on round 4 |

Files: `results/t2-hubB-3feathers-roundrobin.txt` (stopped at round 15),
`results/t2-hubB-4feathers-roundrobin.txt` (stopped at round 19).

### New hypothesis: STEMMA QT back-feed into the unpowered controller

Re-reading the runs, the Adalogger's STEMMA QT cable was **off** for both clean
runs (Realtek 0/30; hub A USB-C only 0/30, confirmed by the "No pull up found"
error right after) and **connected** for every run with BOOTROM boots. The
barrel jack changed at the same time as the cable, so the earlier "external
power" conclusion is confounded.

Mechanism from the Rev C schematic: Q2 (BSS138DW) gates tie to the hub's
3.3 V; hub-side SDA/SCL pull up to 3.3 V through R5 (10K); QT-side SDA_QT/SCL_QT
pull up through R5 (10K) to `VCC`, which is STEMMA V+, i.e. the controller's
own 3.3 V rail. With port 4 off, SDA_QT/SCL_QT fall, the FETs conduct, and the
hub's 3.3 V feeds the Adalogger's 3.3 V rail through about 10K + 10K per line
(plus the RP2040 pin clamp diodes). The rail would not reach 0 V during
"off"; a flash chip that never sees a full power-down may not be ready at the
next boot and the RP2040 falls back to the ROM bootloader. Unmeasured.

Tests: (1) meter on the Adalogger 3V pin with port 4 held off, cable in vs
out; (2) cycle port 4 to first BOOTROM with the cable unplugged.

### Back-feed measured, 2026-09-27: CONFIRMED

Port 4 held off (`0000 off`, Adalogger gone from the bus), meter on the
Adalogger 3V pin to GND:

| STEMMA QT cable Adalogger to hub STEMMA1 | 3V pin with its port off |
|---|---|
| connected | **0.98 V** |
| unplugged | about 0 V ("nothing") |

The hub back-feeds an unpowered controller's 3.3 V rail through the STEMMA QT
lines. Still to show: that removing the cable removes the BOOTROM boots
(cycle test with the cable unplugged).
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

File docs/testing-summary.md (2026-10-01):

# Port Authority 4-port hub: testing summary

Smart HIL Hub Rev C, first 10-board JLC run. Tested 2026-09-24 to 2026-10-01
on Linux (bene, Ubuntu 26.04) and macOS (Mac mini M4 Pro). Details in
`test-log.md` and `findings.md`; scripts, cases and photos in
<https://github.com/mikeysklar/hil-hub-port-authority>.

## Concerns

### 1. STEMMA QT back-feeds an unpowered I2C controller

- With the controller's own port switched off, the hub's I2C lines held its
  3.3 V rail at 0.98 V (0 V with the cable out).
- On a Feather RP2040 Adalogger this caused about 1 in 10 power-ons to land
  in the ROM bootloader. 70/70 clean with the cable unplugged.
- Same result on two hubs with two different 5 V supplies.
- Path: hub 3.3 V, hub-side pull-up, BSS138 body diode, STEMMA-side
  pull-up, STEMMA V+, controller rail.
- With only the cable's V+ wire cut: rail 0 V with the port off, 33/33
  clean power-ons (2026-10-01). V+ is the path that matters; SDA/SCL alone
  did not back-feed the Adalogger.
- **Suggested fix, later rev (ladyada):** a diode on STEMMA1 V+, controller
  to hub only. Keeps pass-through power to STEMMA2. Controller goes on
  STEMMA1, add-ons such as an OLED on STEMMA2; mark it on the silkscreen.
  Still to check: a real Schottky in place of the cut wire, and controllers
  with their own I2C pull-ups. Fuller option: an I2C buffer that isolates
  when either side is unpowered (PCA9517A, TCA9617A, unchecked).
- **Now, in the guide:** keep the I2C controller always powered (a port that
  is never switched, or another hub), or unplug the STEMMA cable before
  cutting its port.

### 2. A chained hub with a Feather ESP32 V2 never comes back after its upstream port is cut

- Hub B on hub A port 4. Cutting and restoring port 4 power-cycles hub B.
  With an ESP32 V2 on hub B, hub B enumerates, fails about 0.1 s later
  (`hub_ext_port_status failed (err = -71)`), disconnects, and repeats
  forever.
- Fine: hub B empty (6/6), Feather RP2040 (5/5), USB thumb drive (5/5),
  and the V2 on the top-level hub (days of use, survives hub resets).
- Ruled out: hub B's supply (fails bus-powered and on its barrel), a stuck
  hub B, Linux autosuspend, and current (same ~900 mA capacitor spike as an
  RP2350; the V2's only extra is a ~140 mA burst about 1 s later).
- Suspect, untested: the V2's CH9102 USB-serial chip connects at full speed
  the instant it gets power, while hub B is still starting up.
- **Workaround:** keep USB-serial boards on the top-level hub, use chained
  hubs for native-USB boards, and power-cycle the board's own port rather
  than the port feeding a chained hub.

## Tested, works

- Per-port power with uhubctl on Linux and macOS (Homebrew 2.6.0), no sudo.
  Clean cutoffs on two hubs: port reads `0000 off`, VBUS 0.000 V.
- Power cycling Feather M0, RP2040, RP2350 and ESP32 V2; RP2350 30/30 with a
  Debug Probe attached.
- Current monitoring, ports 1-3: channel N = port N, no crosstalk;
  1.15-1.17 A where a USB meter read 1.2 A.
- At least 1.17 A per port continuously (battery pack, 30 s, no fault).
- Green port LEDs follow port power.
- SW1 hub reset; external 5 V hot-plug.
- DIP `0 0 0 1` reports Bus Powered.
- STEMMA2 pass-through and an SSD1306 OLED status display (live V/mA per
  port, on/off for all four).
- SWD through the hub: Feather RP2350 attach, halt, flash and verify in
  11.2 s with a Raspberry Pi Debug Probe.
- USB chaining: nested `uhubctl -l 1-1.4` paths and per-port switching on
  the second hub, with the restriction in concern 2.
- EEPROM mode (DIP `1 1 1 1`) once programmed: `eeprom_write.py` wrote
  custom strings, and the hub enumerates as Adafruit Industries / Port
  Authority / serial `PA-A`. The serial lets scripts tell hubs apart.

## Tested, doesn't work

- SMBus DIP mode (`1 1 1 0`): hub stays off USB, never answers at 0x2C,
  host sees a failed low-speed device at every reset. Parked.
- EEPROM mode with the EEPROM as shipped (blank, all `0xFF`): same failure.
  Fixed by programming it (see above).
- Raspberry Pi 4 with an external drive on one port: 0.65 A idle, peaks to
  1.24 A; the port sagged to 3.87 V and the Pi browned out and rebooted
  twice with no fault shown. Power Pi-class loads separately.

## Untested

- I2C chaining of two hubs (needs the second hub's INA3221 A0 jumper bridged
  for 0x41).
- Red fault LED: never triggered, no load exceeded the port limit. Not
  pursued, since the ports already carry more than 1 A.
- JST-XH per-port connectors.

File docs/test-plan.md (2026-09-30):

# Port Authority (Smart HIL Hub Rev C): test plan

Design reference: `design/Smart HIL Hub Rev C.sch` at `461a9006b` (matches the
JLC order). Host: bene.local, hub at USB path `1-2`. Only touch hub `1-2`;
the `1-6` tree on bene has other boards on it.

Each test records command, verbatim output, pass/fail in `test-log.md`, and
the media listed for the guide in `media/`. Anything intermittent gets 10+
trials. Steps marked **[you]** are physical or need sudo.

## Equipment

| Item | Have? | Used by |
|---|---|---|
| Rev C hub on bene `1-2` | yes | all |
| Feather RP2040 Adalogger (CP 10.3.0) as I2C controller | yes | T4-T7, T11, T12 |
| STEMMA QT cable x2 | ? | T4, T11, T12 |
| STEMMA QT OLED (0x3C) | ? | T4, T12 |
| USB power meter (inline USB-A) | ? | T5 |
| Load: Smart HIL Load, or USB load resistor ~0.5 A and >1 A | ? | T5, T6 |
| Regulated 5 V supply, barrel 2.1 mm and bare leads | ? | T8 |
| Second Rev C hub | yes (9 spare) | T11 |
| Target boards for ports 1-3 | ? | T2, T16 |
| Raspberry Pi Debug Probe (on bene `1-6.3.1`) | yes | T16 |
| Mac with a free USB port | yes | T15 |

## Setup

S1. **[you]** Photo the DIP switch and note positions 1-4. Expected for
normal use: all off (CFG_SEL 00).
S2. **[you]** Move the Adalogger to **port 4** (unmonitored). Cable from
Adalogger STEMMA QT to hub STEMMA1.
S3. Update `uhubctl` status and the Adalogger's by-path tty in the notes
(`1-2.4`).

## T1. Enumeration and descriptors

`lsusb -v -d 0424:2514`, `uhubctl -l 1-2`, `lsusb -t`.

Pass: `0424:2514`, 4 ports, `ppps`, Multi-TT (`bDeviceProtocol 2`), and
self-powered bit in `bmAttributes` matches CFG_SEL (00 = self, 10 = bus).
Record whether `LOCAL_PWR` (only a 100K pull-down in Rev C) changes anything
when on external 5 V (cross-check in T8).

Media: terminal session.

## T2. Per-port power switching

For each port 1-4 with a target board: 10 cycles of off, check `0000 off` and
device gone, on, device back, REPL `reset_reason == POWER_ON`. Reuse
`cycle10.py` with the port and by-path tty parameterized. Use `-S`.

Control: one `microcontroller.reset()` per port must read `SOFTWARE`, proving
the check can fail.

Also: switching one port leaves the other three devices untouched (devnums
unchanged).

Pass: 40/40 plus controls. Media: terminal session, GIF of a board LED going
dark and back.

## T3. Settle time

Per port, 10 trials: time from `-a on` to (a) device on bus, (b) tty present,
(c) REPL answers, (d) CIRCUITPY mounted (bene desktop automount).

Pass: numbers only, report min/median/max. Feeds the "wait N seconds" advice
in the guide.

## T4. I2C bus and STEMMA pass-through

From the Adalogger REPL: `board.STEMMA_I2C()` scan.

| DIP state | Expected addresses |
|---|---|
| 2, 3 off | 0x40 (INA3221) only |
| 2, 3 on, 1 on | 0x40, 0x50 (EEPROM), 0x2C only if in SMBus mode |

Then plug the OLED into hub **STEMMA2**: 0x3C appears. Proves the pass-through.

Media: photo of cabling, terminal session.

## T5. Current monitoring (INA3221)

1. Channel map: load on port 1, see which channel moves; repeat ports 2, 3.
   Port 4 must show nothing on any channel.
2. Accuracy: idle target board, then ~0.5 A load, INA3221 vs USB power meter,
   each port. 10 readings each.
3. Port off: channel reads ~0 mA.
4. Bus voltage per channel, idle and loaded (shunt is 0.1 ohm, expect about
   0.05 V drop at 0.5 A).

Library: `adafruit_ina3221`. Pass: channel map documented, readings within
meter tolerance plus INA spec. Media: code block, terminal session, photo.

## T6. LEDs and over-current

1. Green follows uhubctl on/off, each port. GIF.
2. **Gated, ask first:** >1 A load on one port. Expect AP22653 limit, red LED,
   `uhubctl` port status shows over-current, other ports unaffected. Only with
   a defined load, never a short, and never above ~4 A total.

## T7. Hub reset (SW1 and JP1)

SW1 to hold: hub and all downstream drop off the bus; back to run: all return.
JP1 pad to GND briefly: same. Needed later to latch DIP changes.

Media: terminal session showing `lsusb -t` before/during/after.

## T8. Power input

1. USB-only: all 4 ports on with loads, measure VBUS at a port.
2. **[you]** 5 V on the DC jack: re-run T1 `bmAttributes`, measure port VBUS.
   Terminal block the same.
3. Hot switch-over: remove external 5 V while boards run on ports. Do targets
   brown out or ride through?

Pass: behavior documented. UVLO/OVLO threshold tests only with an adjustable
supply, optional.

## T9. DIP configuration modes

Latch each with SW1 reset. Back up EEPROM before any write.

| Mode | SW2 | Test |
|---|---|---|
| 00 default | all off | baseline, done in T1 |
| 10 bus-powered | 4 on | `bmAttributes` shows bus-powered |
| 11 EEPROM | 1, 2, 3, 4 on | read EEPROM (0x50) from Adalogger, save image. If blank, write a config with custom product string, reset, confirm in `lsusb -v` |
| 01 SMBus | 2, 3 on | hub stays off the bus until configured. Write registers + attach at 0x2C from Adalogger, confirm enumeration |

Note: in 01 and 11 the Adalogger shares the bus with the hub at reset time.
Keep it idle on the bus during hub reset.

Media: code blocks for EEPROM read/write and SMBus attach, terminal sessions.

## T10. JST-XH port and upstream headers (optional)

Continuity check of one port XH against its USB-A. Document pinout, with the
footprint quirk that schematic pin 1 is JST wire 4.

## T11. Chaining

1. USB cascade: second hub into port 3. `uhubctl` shows `1-2.3` as a hub;
   switch a port on it; switch port 3 on the first hub and the whole second
   hub drops.
2. I2C chain: first hub STEMMA2 to second hub STEMMA1. Scan shows two 0x40
   devices colliding. **[you]** bridge A0 on the second hub, scan shows 0x40
   and 0x41. Read both INA3221s.

Media: photo of two hubs, terminal sessions.

## T12. Display

OLED on STEMMA2, `code.py` on the Adalogger showing per-port mA and on/off.
GIF while uhubctl switches ports 1-3.

Media: code block, GIF.

## T13. SWD / openocd through the hub

1. Debug Probe (bene `1-6.3.1`) SWD to a target on a hub port.
2. Workflow: `uhubctl` cycle the target, openocd attach, halt, read a
   register, resume. Also the recovery loop: a wedged target is recovered by
   port power cycle alone.
3. Board-specific notes table from `mounted-hil-farm/FARM-REFERENCE.md`:
   RP2040, RP2350, SAMD21/51, nRF52840, STM32F405, ESP32-S2/S3. Mark which
   were exercised on this hub vs carried over from bravo.

Media: terminal sessions, photo of probe wiring.

## T14. macOS

1. `brew install uhubctl`. Hub on the Mac directly.
2. `uhubctl` list, switch port 1 off/on, 10 cycles with a board attached.
3. Record: sudo needed or not, whether the Mac re-enumerates cleanly, any
   `-S`/libusb messages, Apple Silicon quirks.

Media: terminal session.

## T15. Linux host setup page

Reproduce `bene-setup.md` as the guide's setup page, with the single-line
udev rule and a note on the sysfs `disable` permission warning and `-S`.

## Order

S1-S3, T1, T7, T2, T3, T4, T5, T12, T6, T8, T9, T11, T13, T14, T10, T15.
Read-only and low-risk first; over-current, power input and EEPROM writes last.

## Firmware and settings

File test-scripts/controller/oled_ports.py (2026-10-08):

# Port Authority I2C controller: live port status on an SSD1306 128x64 OLED.
# T12. Deploy as code.py on the controller. OLED on hub STEMMA2 (0x3D,
# Adafruit 326 / 938), INA3221 at 0x40 on the same bus.
# Ports 1-3: bus voltage and current from the INA3221 (raw register reads,
# same math as ina3221_volts.py). Port 4 has no INA channel.
# On/off for all four ports comes from the host: oled_push.py sends
# "PA 1101\n" (port 1..4 power, from uhubctl) over USB serial. If no update
# arrives for STALE_S, on/off shows "?".
# Adafruit IO: every AIO_S, posts ports 1-3 mA to feeds pa.port1-ma ..
# pa.port3-ma over HTTP. HTTP posts do not create feeds: make group "pa"
# and the three feeds first. Needs CIRCUITPY_WIFI_SSID/PASSWORD and
# ADAFRUIT_AIO_USERNAME/KEY in settings.toml; without the AIO keys it only
# drives the OLED. Post status shows on the title line.
# Needs adafruit_displayio_ssd1306, adafruit_display_text, adafruit_requests
# and adafruit_connection_manager (11.x bundle).
import os
import sys
import time
import board
import displayio
import i2cdisplaybus
import supervisor
import terminalio
import wifi
from adafruit_display_text import label
import adafruit_connection_manager
import adafruit_displayio_ssd1306
import adafruit_requests

INA = 0x40
STALE_S = 5
AIO_S = 60
AIO_USER = os.getenv("ADAFRUIT_AIO_USERNAME")
AIO_KEY = os.getenv("ADAFRUIT_AIO_KEY")
displayio.release_displays()
i2c = board.STEMMA_I2C()
bus = i2cdisplaybus.I2CDisplayBus(i2c, device_address=0x3D)
display = adafruit_displayio_ssd1306.SSD1306(bus, width=128, height=64)

group = displayio.Group()
title = label.Label(terminalio.FONT, text="Port Authority", x=0, y=4)
group.append(title)
rows = []
for n in range(4):
    row = label.Label(terminalio.FONT, text="", x=0, y=16 + 12 * n)
    group.append(row)
    rows.append(row)
display.root_group = group

b = bytearray(2)
power = "????"
last_push = None
line = ""
ma_now = [None] * 3
last_aio = -AIO_S
requests = None
if AIO_USER and AIO_KEY:
    pool = adafruit_connection_manager.get_radio_socketpool(wifi.radio)
    ssl = adafruit_connection_manager.get_radio_ssl_context(wifi.radio)
    requests = adafruit_requests.Session(pool, ssl)


def reg(n):
    while not i2c.try_lock():
        pass
    try:
        i2c.writeto_then_readfrom(INA, bytes([n]), b)
    finally:
        i2c.unlock()
    v = b[0] << 8 | b[1]
    return v - 0x10000 if v & 0x8000 else v


def read_host():
    global line, power, last_push
    while supervisor.runtime.serial_bytes_available:
        c = sys.stdin.read(1)
        if c in "\r\n":
            if line.startswith("PA ") and len(line) == 7:
                power = line[3:]
                last_push = time.monotonic()
            line = ""
        else:
            line = line[-16:] + c


def state(p):
    if last_push is None or time.monotonic() - last_push > STALE_S:
        return "?  "
    return {"1": "on ", "0": "off"}.get(power[p], "?  ")


def post_aio():
    if not wifi.radio.connected:
        return "noWiFi"
    url = "https://io.adafruit.com/api/v2/%s/feeds/pa.port%d-ma/data"
    for ch in range(3):
        if ma_now[ch] is None:
            continue
        try:
            with requests.post(url % (AIO_USER, ch + 1), headers={"X-AIO-Key": AIO_KEY},
                               json={"value": round(ma_now[ch], 1)}) as r:
                if r.status_code != 200:
                    return "AIO %d" % r.status_code
        except Exception:  # adafruit_requests can raise ValueError on a garbled reply
            return "AIOerr"
    return "AIO"


while True:
    read_host()
    for ch in range(3):
        try:
            volts = (reg(2 + 2 * ch) >> 3) * 0.008
            ma = (reg(1 + 2 * ch) >> 3) * 40e-6 / 0.1 * 1000
            rows[ch].text = "P%d %s %4.2fV %5.1fmA" % (ch + 1, state(ch), volts, ma)
            ma_now[ch] = ma
        except OSError as e:
            ma_now[ch] = None
            rows[ch].text = "P%d %s read err %d" % (ch + 1, state(ch), e.errno)
    rows[3].text = "P4 %s   (no INA)" % state(3)
    if requests and time.monotonic() - last_aio >= AIO_S:
        last_aio = time.monotonic()
        title.text = "Port Authority " + post_aio()
    time.sleep(0.2)

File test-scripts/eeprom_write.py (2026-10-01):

"""T9d: write a USB2514B config image with custom strings to the hub's 24LC02.

usage: python3 eeprom_write.py [hub] [manufacturer] [product] [serial] [--dry-run]
  default: 1-1 "Adafruit Industries" "Port Authority" "PA-A"
Controller: PA_CTRL=<usb path>, or hub port 4 (it must stay powered, so not
on the hub being programmed when that hub is held in reset).

Before running: DIP 1 2 3 on, 4 off, and SW1 slid OFF to hold the hub in
reset, so the hub leaves the EEPROM bus alone. After: DIP 4 on (1 1 1 1) and
SW1 ON; the hub then loads this image. DIP 0 0 0 0 ignores the EEPROM again.

Image = datasheet DS00001692C section 5.1 default ROM values for the
USB2514B (VID 0424, PID 2514, self-powered, multi-TT, port swap 0x00), plus
STRING_EN (reg 0x08 bit 0), language 0x0409, and UTF-16LE strings of at
most 31 characters. Writes in 8-byte pages with ACK polling, then reads all
256 bytes back and compares. The image is saved to ../results/eeprom-<serial>.bin.
"""
import os, sys
from repl import Repl, ctrl_tty

dry = "--dry-run" in sys.argv
argv = [a for a in sys.argv[1:] if a != "--dry-run"]
args = argv + ["1-1", "Adafruit Industries", "Port Authority", "PA-A"][len(argv):]
hub, mfr, prd, ser = args[:4]

img = bytearray(256)
img[0x00:0x06] = bytes([0x24, 0x04, 0x14, 0x25, 0xB3, 0x0B])  # VID, PID, DID (defaults)
img[0x06] = 0x9B  # CONFIG_BYTE_1 default: self-powered, MTT, EOP disable, per-port power/OC
img[0x07] = 0x20  # CONFIG_BYTE_2 default: OC timer 8 ms
img[0x08] = 0x03  # CONFIG_BYTE_3 default 0x02 | STRING_EN
img[0x09:0x11] = bytes([0x00, 0x00, 0x00, 0x01, 0x32, 0x01, 0x32, 0x32])  # NR, port dis, power, power-on time
img[0x11], img[0x12] = 0x04, 0x09  # language ID 0x0409 (English US), high then low
for name, s, lenreg, start in (("manufacturer", mfr, 0x13, 0x16), ("product", prd, 0x14, 0x54),
                               ("serial", ser, 0x15, 0x92)):
    assert len(s) <= 31, f"{name} string over 31 characters"
    u = s.encode("utf-16-le")
    img[lenreg] = len(s)
    img[start:start + len(u)] = u
# 0xD0 battery charging, 0xF6/0xF8 boost, 0xFA port swap, 0xFB/0xFC port map: all 0 (defaults)

os.makedirs("../results", exist_ok=True)
fn = f"../results/eeprom-{ser}.bin"
open(fn, "wb").write(img)
for base in range(0, 256, 16):
    print("IMG %02x:" % base, " ".join("%02x" % x for x in img[base:base + 16]))
print("saved", fn)
if dry:
    sys.exit(0)

r = Repl(ctrl_tty(hub, "4"))
print("synced:", r.sync())
out = r.paste(f"""
import board, time, binascii
img = binascii.a2b_base64("{__import__('base64').b64encode(img).decode()}")
try:
    i2c.deinit()
except Exception:
    pass
i2c = board.STEMMA_I2C()
while not i2c.try_lock():
    pass
try:
    print("SCAN", [hex(a) for a in i2c.scan()])
    retries = 0
    for page in range(0, 256, 8):
        # a page write can be NACKed now and then (seen once at 0x58);
        # rewriting a page is harmless, so retry it, then ACK-poll the write cycle
        for attempt in range(5):
            try:
                i2c.writeto(0x50, bytes([page]) + img[page:page + 8])
                break
            except OSError:
                retries += 1
                time.sleep(0.01)
        else:
            raise OSError("page 0x%02x not acknowledged after 5 tries" % page)
        # monotonic_ns: time.monotonic() is a float that gets too coarse after
        # days of uptime to time a 50 ms window
        t0 = time.monotonic_ns()
        while True:
            try:
                i2c.writeto(0x50, bytes([page]))
                break
            except OSError:
                if time.monotonic_ns() - t0 > 50_000_000:
                    raise
    print("RETRIES", retries)
    back = bytearray(256)
    for base in range(0, 256, 16):
        b = bytearray(16)
        i2c.writeto_then_readfrom(0x50, bytes([base]), b)
        back[base:base + 16] = b
    bad = [i for i in range(256) if back[i] != img[i]]
    print("VERIFY", "OK" if not bad else "MISMATCH at " + ",".join(hex(i) for i in bad[:16]))
finally:
    i2c.unlock()
    i2c.deinit()
""", wait=20)
print("\n".join(l for l in out.splitlines() if l.startswith(("SCAN", "VERIFY")) or "Error" in l))
r.close()

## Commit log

2026-09-30 Port Authority hub bench notes, test scripts and cases
    Claude-Session: https://claude.ai/code/session_013nrULWDVvhWmTyoWPz2Wuz
    [bottom_plate.step, sandwich_case-BottomPlate.3mf, sandwich_case-TopPlate.3mf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]
2026-09-30 Add case and OLED photos to README
    Photos resized to 640 px, EXIF/GPS and embedded secondary images removed.
    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
2026-10-01 Update findings and test log: chaining, OLED, STEMMA2
    Chaining works with a restriction: a chained hub with an ESP32 V2 attached
    loops after its upstream port is cut. STEMMA2 pass-through and the OLED
    status display now marked as working.
    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
2026-10-01 Add chaining and inrush scripts, update README for chaining
    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
2026-10-01 Add macOS, port current and LED results
    Ports carry at least 1.17 A; Pi 4 with a drive browns out at peaks;
    INA3221 within ~5% of a USB meter; macOS works with Homebrew uhubctl.
    Adds ina_watch.py.
    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
2026-10-01 EEPROM programming works; shorter README; add testing summary
    Hub enumerates from a programmed EEPROM (DIP 1111) with custom
    manufacturer, product and serial strings. Adds eeprom_write.py.
    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
    [eeprom_write.py]
2026-10-01 STEMMA V+ cut results and diode fix
    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
2026-10-05 Add display case: top plate with QT Py and OLED, rail frame
    Sandwich-style top plate on M2.5 x 5 standoffs with heat-set inserts
    for a 0.96" OLED (on 8 mm standoffs, tab past the top edge) and a
    printed QT Py ESP32-S3 cradle with USB-C out the left edge. Back rail
    frame with flush inserts, no hook notches.
    [display_case.FCStd, frame.step, qtpy_cradle.step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]
2026-10-05 Display case: raised insert bosses, SKADIS nicks, SW1 access
    Printed bosses replace bought standoffs: the frame bosses carry the
    inserts and space the board off the rails, the plate stands on bosses
    at the hub holes (one M2.5 x 12 per hole), and the OLED sits on 8 mm
    printed spacers. Bottom rail gets two 5.5 x 2 mm nicks 120 mm apart
    for SKADIS hooks. Plate opens over SW1 and out the right edge.
    [display_case.FCStd, frame.step, qtpy_cradle.step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]
2026-10-05 Display case: flat plate underside, inserts in QT Py cradle
    Drop the bosses under the top plate so it prints face down. The hub
    goes back to bought M2.5 x 5 male-female standoffs into the frame
    inserts, and the QT Py cradle carries its own inserts in a 4 mm floor
    with screws coming up through the plate. Add the 3MF print files.
    [display_case-Frame.3mf, display_case-QtCradle.3mf, display_case-TopPlate.3mf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]
2026-10-05 Display case: QT Py cradle built into the top plate
    Merge the cradle into the plate so the QT Py needs no screws or
    inserts; a plate tab under it carries it past the left edge. Loosen
    the fit (0.4 mm side clearance, 0.5 mm under the lips) and thicken
    the lips and walls. Top plate STL now exports underside down.
    [display_case-Frame.3mf, display_case-QtCradle.3mf, display_case-TopPlate.3mf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]
2026-10-05 Remove QT Py cradle 3MF, the cradle is part of the top plate
    [display_case-QtCradle.3mf]
2026-10-07 OLED controller: post port current to Adafruit IO
    Every 60 s the controller posts ports 1-3 mA to feeds pa.port1-ma ..
    pa.port3-ma over HTTP, using the WiFi and AIO settings in settings.toml.
    Status shows on the title line. Without AIO settings it only drives
    the OLED.
2026-10-08 OLED controller: keep running when an AIO post fails
    adafruit_requests 4.1.17 raised ValueError parsing a garbled HTTP status
    line, which post_aio did not catch, so code.py exited and the host's
    "PA" lines landed in the REPL. Catch any exception and show AIOerr.
    [oled_ports.py]
2026-10-08 README: OLED case hero photo linking to the video
